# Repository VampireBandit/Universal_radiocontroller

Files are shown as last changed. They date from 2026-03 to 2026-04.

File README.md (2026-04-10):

# Transceiver_101
This is a universal remote controller for almost any remote device e.g. Planes,drones,boats or rc cars. It can be mounted and set up in any custom project the needs remote controlling.
---
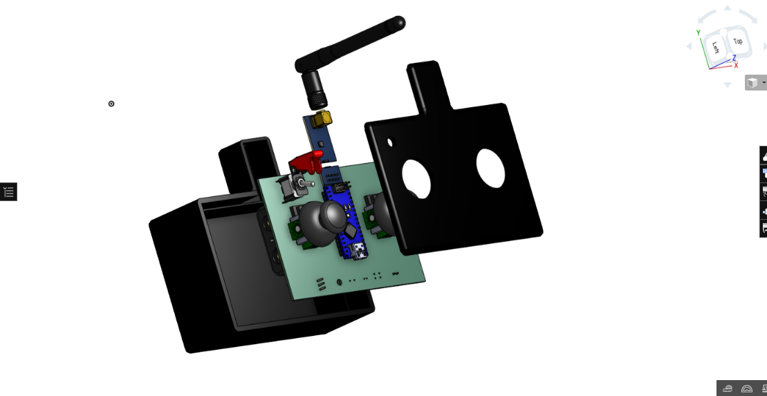
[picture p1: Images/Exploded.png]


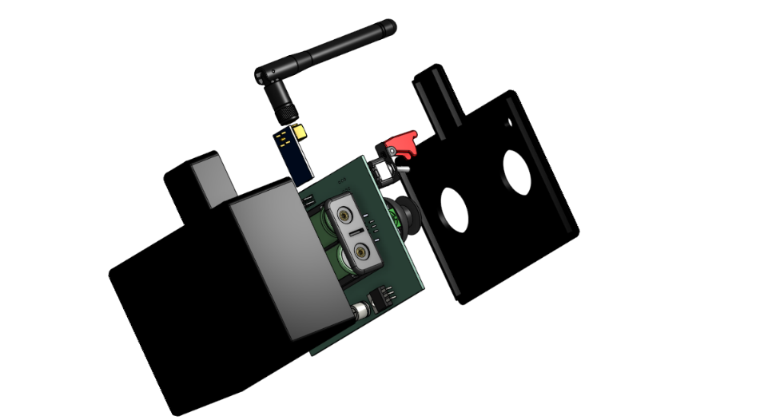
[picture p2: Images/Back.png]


# Key Features 
-can be used to controll almost any project

-customisable for drone flight controllers

-6 channel controller

-up to 2.5km range 

-2 customizable toggle switch

-Custom code to change as needed

# Images

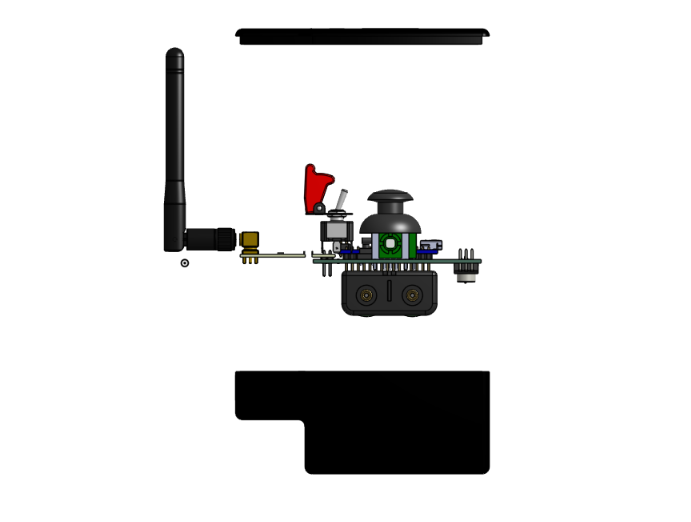
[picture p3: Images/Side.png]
h


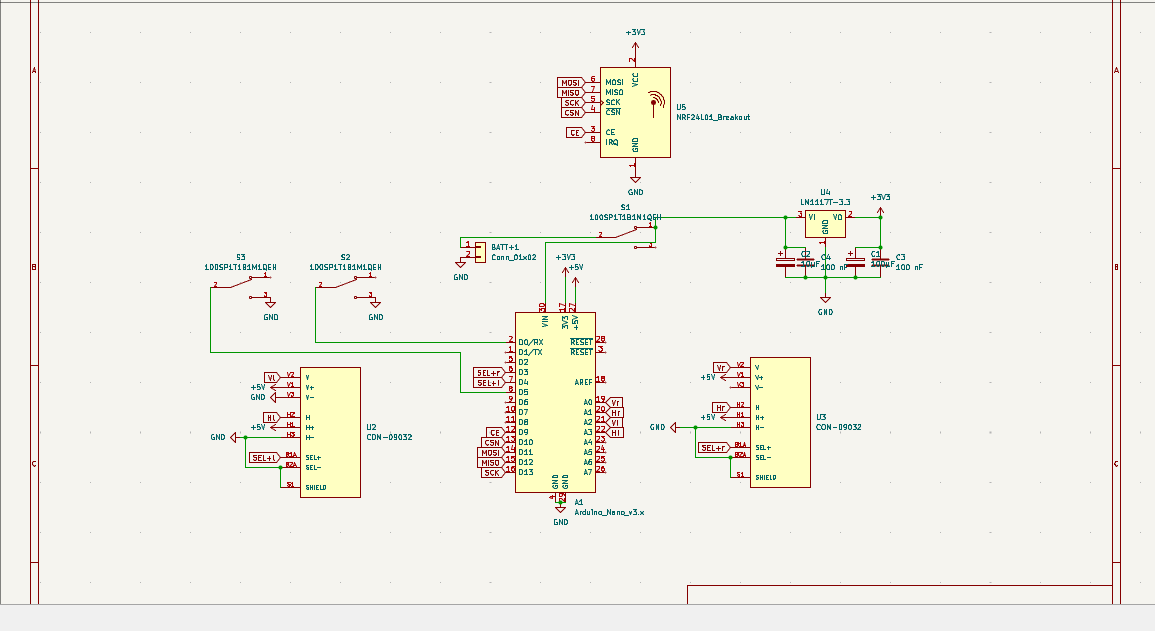
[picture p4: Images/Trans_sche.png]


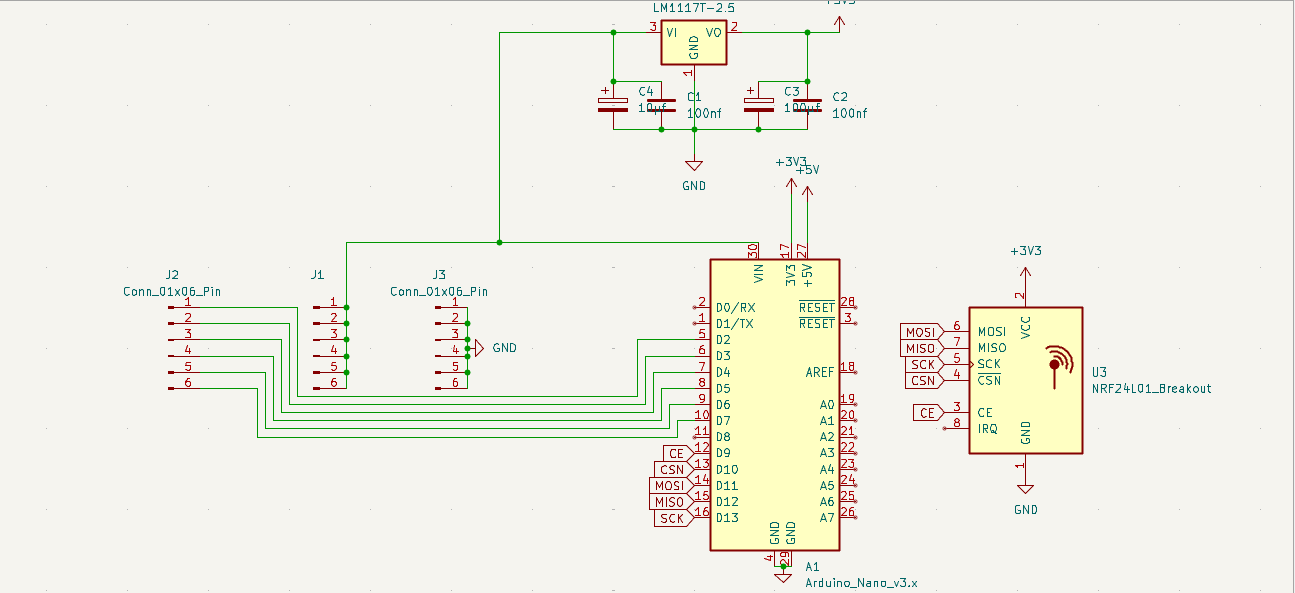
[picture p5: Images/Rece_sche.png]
v


fvg

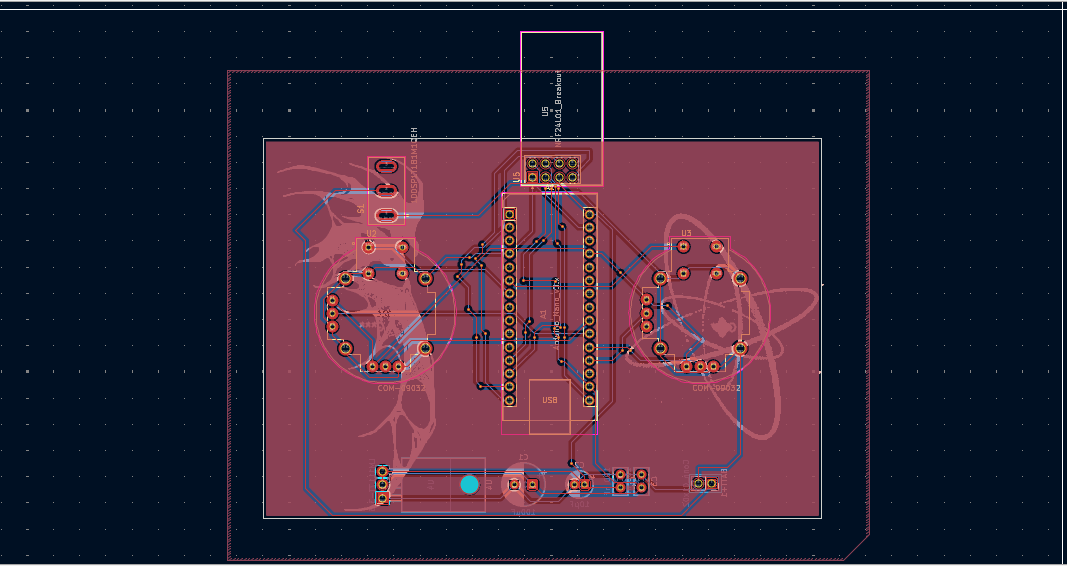
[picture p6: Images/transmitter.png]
g


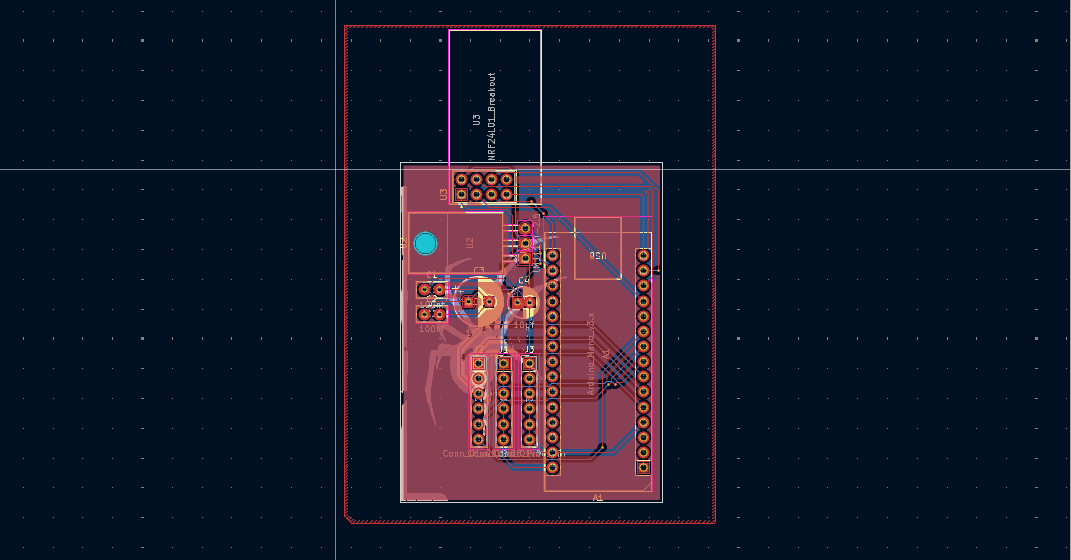
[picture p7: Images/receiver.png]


There is a notch that shuold be kept in mind. 

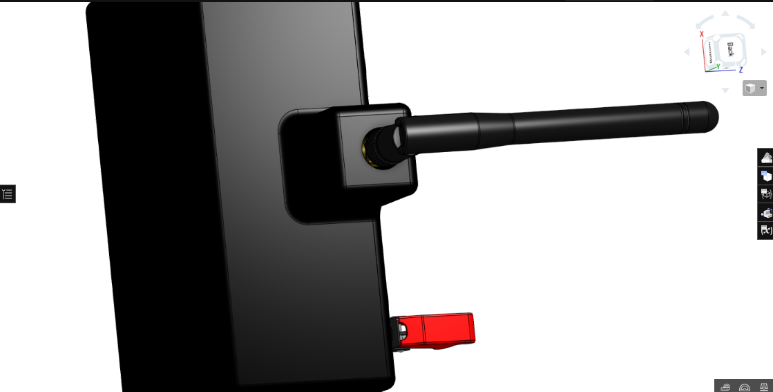
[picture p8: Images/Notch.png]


# BOM

| Name | Purpose | Quantity |
| :--- | :--- | :--- |
| **Toggle switch** | Master power | 1 |
| **PCB** | Circuit board | 2 |
| **Enclosure** | The casing | 1 |
| **Battery** | Power | 2 |
| **Male headers** | Connection | 8 |
| **Female Headers** | Mounting | 56 |
| **100nf capacitor** | Voltage capping | 4 |
| **10uf capacitor** | Voltage regulation | 2 |
| **100uf capacitor** | Voltage regulation | 2 |
| **Arduino Nano** | MCU | 2 |
| **Antenna** | Receiver antenna | 1 |
| **Receiver Module** | Radio transmission | 1 |
| **LM1117T-3.3** | Voltage regulator | 2 |
| **Toggle switch** | Channel switch | 2 |
| **PS4 Analog** | Controlling | 2 |

# Firmware
This remote and receiver uses C++ that is for arduino IDE

Made by Rubaiyat Islam

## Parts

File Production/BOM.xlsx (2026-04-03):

Component | Link | Quantity | Unit Price | Total | With Shipping
Arduino Nano | https://s.click.aliexpress.com/e/_DlhwLS3 | X2 | $2.07 | $4.14 | $4.64
NRF24L01+PA+LN 100mW (E01-ML01DP5) | https://s.click.aliexpress.com/e/_DmEoWQf | X1 | $4.37 | $4.37 | $8.44
NRF24L01+PA+Wireless SMD | https://www.aliexpress.com/item/4001032051571.html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 | X1 | $2.11 | $2.11 | $5.62
100uF (16V or above) electrolytic capacitors | https://s.click.aliexpress.com/e/_Ddfia2R | X2 | $1.02 | $2.04 | $3.00
10uF electrolytic capacitors | https://www.aliexpress.com/item/32910379011.html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"order"%3A"1377"%2C"spu_best_type"%3A"price"%2C"eval"%3A"1"%2C"sceneId"%3A"30050"%2C"fromPage"%3A"recommend"%7D&pdp_npi=6%40dis%21USD%210.73%210.66%21%21%210.73%210.66%21%40210385a817732371508048925e73f6%2112000027302961998%21rec%21BD%217350065947%21X%211%210%21n_tag%3A-29911%3Bd%3A8c992529%3Bm03_new_user%3A-29895&utparam-url=scene%3ApcDetailTopMoreOtherSeller%7Cquery_from%3A%7Cx_object_id%3A32910379011%7C_p_origin_prod%3A | X2 | $0.89 | $1.78 | $2.76
100nF (104) ceramic capacitor | https://www.aliexpress.com/item/1005008483990919.html?pdp_ext_f=%7B"order"%3A"2331"%2C"eval"%3A"1"%2C"fromPage"%3A"search"%7D&pdp_npi=6%40dis%21USD%210.44%210.40%21%21%213.03%212.73%21%402140c1e917732495509002759e5e46%2112000045347461268%21sea%21BD%217350065947%21X%211%210%21n_tag%3A-29911%3Bd%3A8c992529%3Bm03_new_user%3A-29895&curPageLogUid=Py6DamOLkBbD&utparam-url=scene%3Asearch%7Cquery_from%3A%7Cx_object_id%3A1005008483990919%7C_p_origin_prod%3A | X2 | $0.43 | $0.86 | $1.47
LM1117 3.3 RegACulator IC | https://www.aliexpress.com/item/1005003271197114.html?pdp_ext_f=%7B"order"%3A"8"%2C"eval"%3A"1"%2C"fromPage"%3A"search"%7D&pdp_npi=6%40dis%21USD%216.04%216.04%21%21%216.04%216.04%21%40211b65de17732372615652759ea03c%2112000026915350926%21sea%21BD%217350065947%21X%211%210%21n_tag%3A-29911%3Bd%3A8c992529%3Bm03_new_user%3A-29895&curPageLogUid=09Xqtkg0wL0p&utparam-url=scene%3Asearch%7Cquery_from%3A%7Cx_object_id%3A1005003271197114%7C_p_origin_prod%3A | X2 | $6.72 | $13.44 | $13.44
2×4 pin Header | https://www.aliexpress.com/item/4000062424172.html?pdp_ext_f=%7B"order"%3A"4"%2C"eval"%3A"1"%2C"fromPage"%3A"search"%7D&pdp_npi=6%40dis%21USD%213.35%212.85%21%21%213.35%212.85%21%402103891017732373337637330ede3c%2110000000158969144%21sea%21BD%217350065947%21X%211%210%21n_tag%3A-29911%3Bd%3A8c992529%3Bm03_new_user%3A-29895&curPageLogUid=POZyNLQOmYaK&utparam-url=scene%3Asearch%7Cquery_from%3A%7Cx_object_id%3A4000062424172%7C_p_origin_prod%3A | X2 | $2.85 | $5.70 | $14.86
2.4G Antenna Adapter Cable | https://www.aliexpress.com/item/4001032051571.html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 | X2 | $1.24 | $2.48 | $4.75
Toggle switch with plastic cover | https://www.aliexpress.com/item/32858842031.html?pdp_ext_f=%7B"order"%3A"1446"%2C"eval"%3A"1"%2C"fromPage"%3A"search"%7D&pdp_npi=6%40dis%21USD%214.57%214.57%21%21%214.57%214.57%21%4021010d9017732489828965303ef2fc%2112000029766731590%21sea%21BD%217350065947%21X%211%210%21n_tag%3A-29911%3Bd%3A8c992529%3Bm03_new_user%3A-29895&curPageLogUid=x4X8XtIfAjth&utparam-url=scene%3Asearch%7Cquery_from%3A%7Cx_object_id%3A32858842031%7C_p_origin_prod%3A | X1 | $5.85 | $5.85 | $5.85
Male Headers | https://www.aliexpress.com/item/1005010337310648.html?pdp_ext_f=%7B"order"%3A"185"%2C"eval"%3A"1"%2C"fromPage"%3A"search"%7D&pdp_npi=6%40dis%21USD%2112.40%215.95%21%21%2184.68%2140.65%21%402140f54217732497921803080ee878%2112000052031729113%21sea%21BD%217350065947%21X%211%210%21n_tag%3A-29911%3Bd%3A8c992529%3Bm03_new_user%3A-29895&curPageLogUid=9He54BdZktP2&utparam-url=scene%3Asearch%7Cquery_from%3A%7Cx_object_id%3A1005010337310648%7C_p_origin_prod%3A | X20 | $0.33 | $6.61 | $4.63
Bottom Casing |  | X1 |  |  | $12.07
Top Casing |  | X1 |  |  | $3.95
Transmitter PCB |  | X1 |  |  | $7.10
Receiver PCB |  | X1 |  |  | $4.00
General Toggle Switch | https://www.aliexpress.com/item/1005010352006465.html?pdp_ext_f=%7B"order"%3A"282"%2C"eval"%3A"1"%2C"fromPage"%3A"search"%7D&pdp_npi=6%40dis%21USD%2117.28%212.29%21%21%21118.28%2115.70%21%402140f53817752205575296309e4e68%2112000052087737430%21sea%21BD%210%21ABX%211%210%21n_tag%3A-29910%3Bd%3A8c992529%3Bm03_new_user%3A-29895%3BpisId%3A5000000203797608&curPageLogUid=lw18lO9RrN7K&utparam-url=scene%3Asearch%7Cquery_from%3A%7Cx_object_id%3A1005010352006465%7C_p_origin_prod%3A | X2 | $4.96 | $10.00 | $10.00
Grand total |  |  |  |  | $106.58

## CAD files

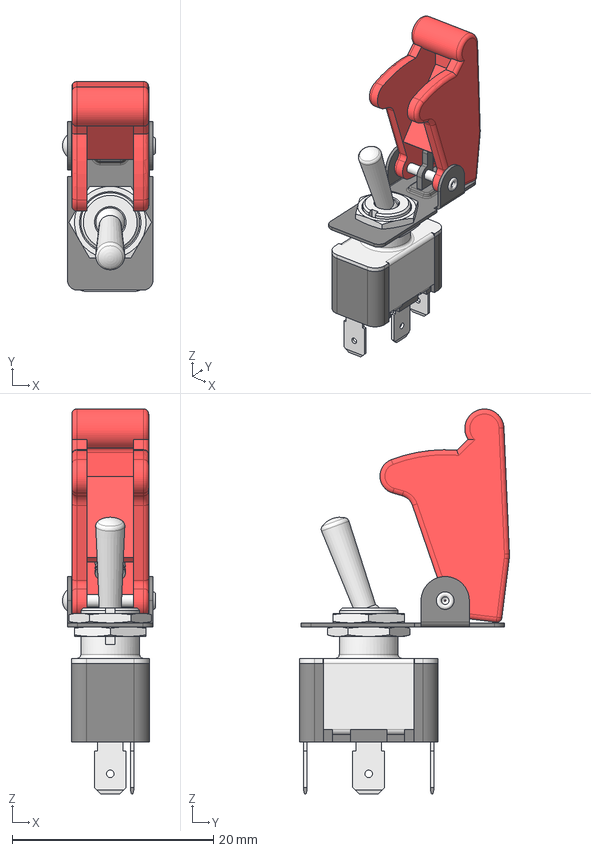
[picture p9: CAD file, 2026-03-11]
CAD/Switch With Guard.step
9.25 x 20.9 x 38.3 mm

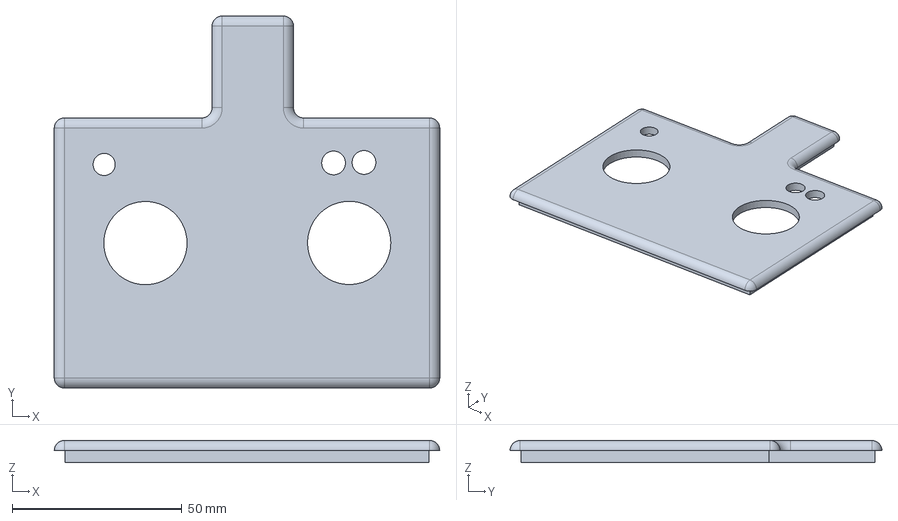
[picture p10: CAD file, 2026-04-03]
Production/TOp.step
113.5 x 109.5 x 6.50 mm

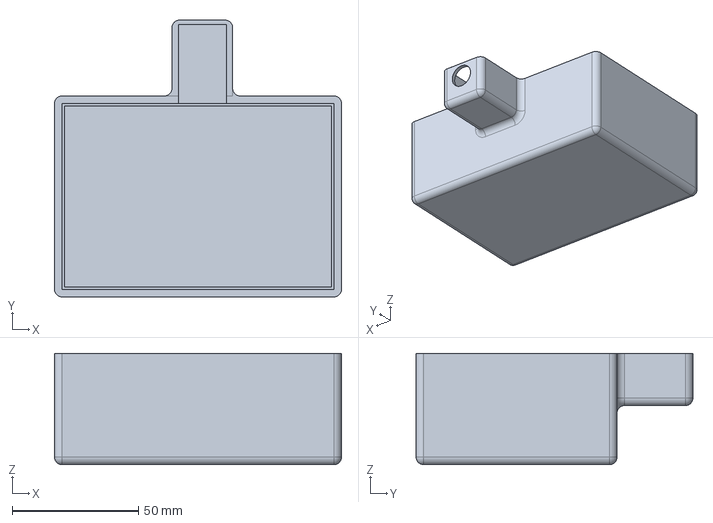
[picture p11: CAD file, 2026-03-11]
CAD/Bottom.step
113.5 x 109.5 x 44.0 mm

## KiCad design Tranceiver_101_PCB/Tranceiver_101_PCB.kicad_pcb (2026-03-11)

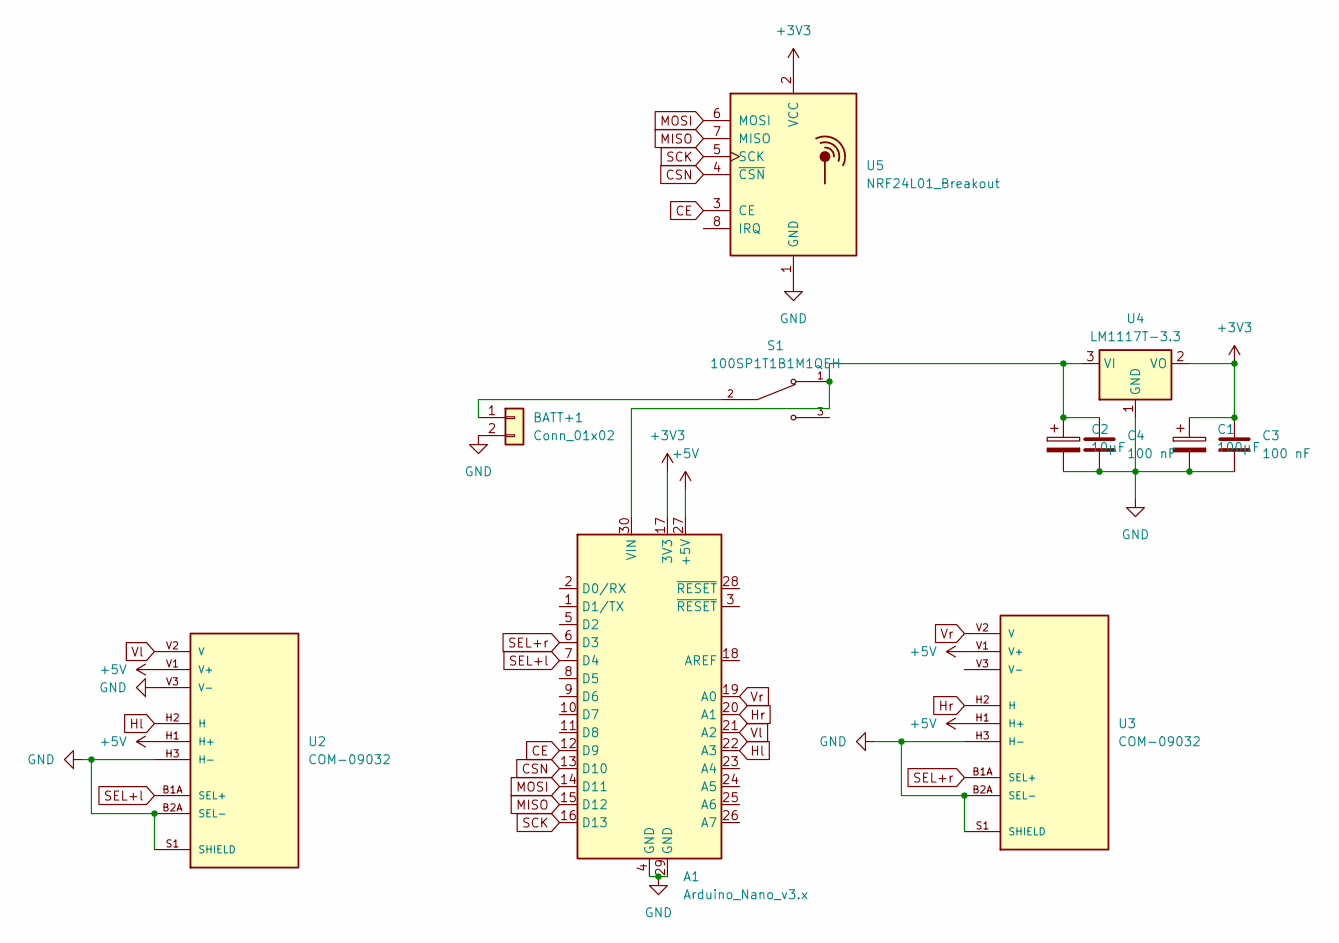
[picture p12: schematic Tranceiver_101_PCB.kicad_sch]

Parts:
A1: Arduino_Nano_v3.x; Arduino_Nano
BATT+1: Conn_01x02; PinHeader_1x02_P2.54mm_Vertical
C1: 100µF; CP_Radial_D8.0mm_P3.50mm
C2: 10µF; CP_Radial_D5.0mm_P2.00mm
C3, C4: 100 nF; C_Disc_D5.0mm_W2.5mm_P2.50mm
S1: 100SP1T1B1M1QEH; SW_100SP1T1B1M1QEH; PARTREV D
U2, U3: COM-09032; XDCR_COM-09032; PARTREV N/A
U4: LM1117T-3.3; TO-220-3_Horizontal_TabDown
U5: NRF24L01_Breakout; nRF24L01_Breakout

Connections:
+3V3: A1.17 (3V3), C1.1, C3.1, U4.2 (VO), U5.2 (VCC)
+5V: A1.27 (+5V), U2.H1 (H+), U2.V1 (V+), U3.H1 (H+), U3.V1 (V+)
CE: A1.12 (D9), U5.3 (CE)
CSN: A1.13 (D10), U5.4 (~CSN)
GND: A1.4 (GND), A1.29 (GND), BATT+1.2, C1.2, C2.2, C3.2, C4.2, U2.B2A (SEL-), U2.H3 (H-), U2.S1 (SHIELD), U2.S2 (SHIELD), U2.S3 (SHIELD), U2.S4 (SHIELD), U2.V3 (V-), U3.B2A (SEL-), U3.H3 (H-), U3.S1 (SHIELD), U3.S2 (SHIELD), U3.S3 (SHIELD), U3.S4 (SHIELD), U4.1 (GND), U5.1 (GND)
Hl: A1.22 (A3), U2.H2 (H)
Hr: A1.20 (A1), U3.H2 (H)
MISO: A1.15 (D12), U5.7 (MISO)
MOSI: A1.14 (D11), U5.6 (MOSI)
unnamed: A1.30 (VIN), C2.1, C4.1, S1.1, U4.3 (VI)
unnamed: BATT+1.1, S1.2
SCK: A1.16 (D13), U5.5 (SCK)
SEL+l: A1.7 (D4), U2.B1A (SEL+)
SEL+r: A1.6 (D3), U3.B1A (SEL+)
Vl: A1.21 (A2), U2.V2 (V)
Vr: A1.19 (A0), U3.V2 (V)

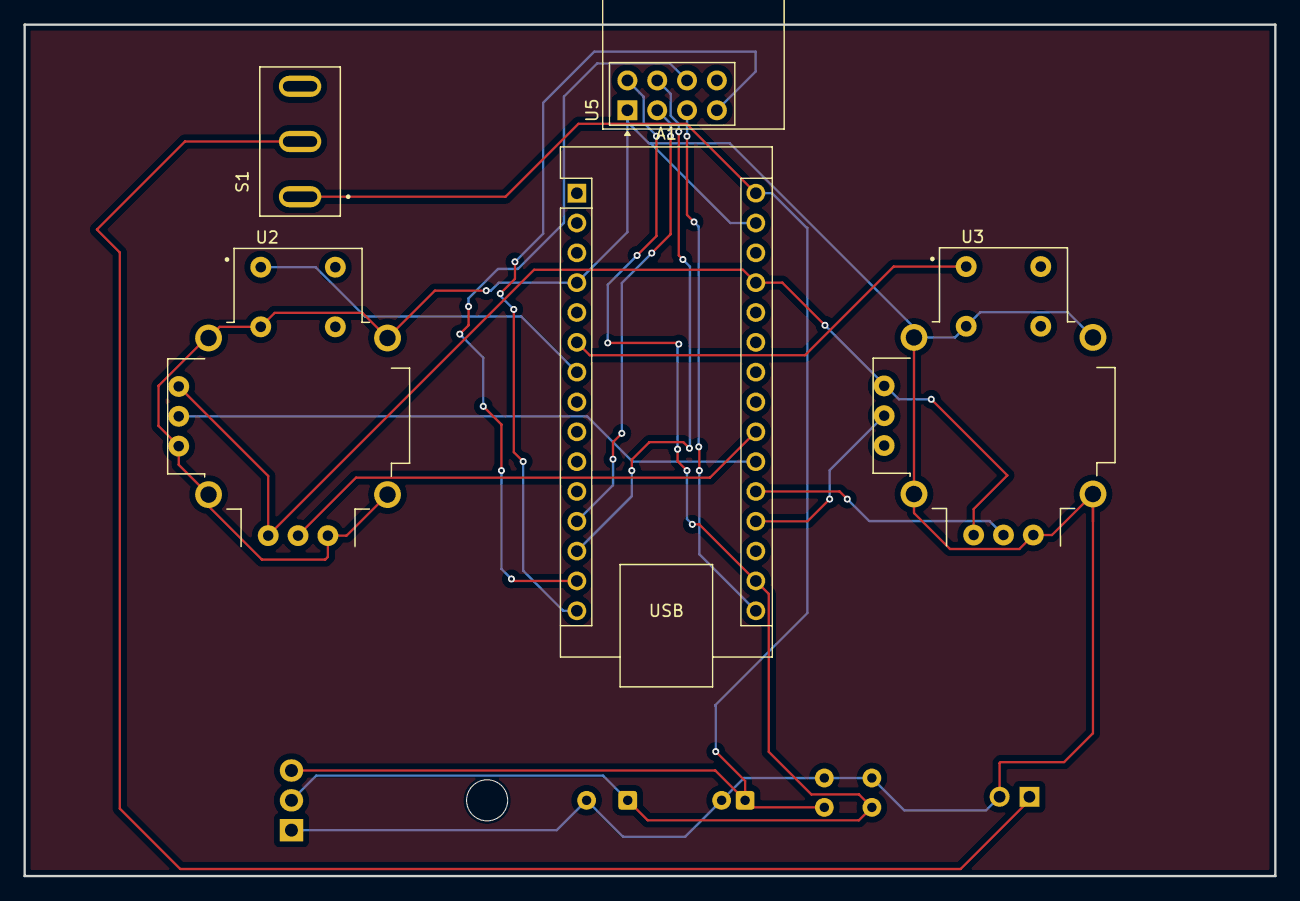
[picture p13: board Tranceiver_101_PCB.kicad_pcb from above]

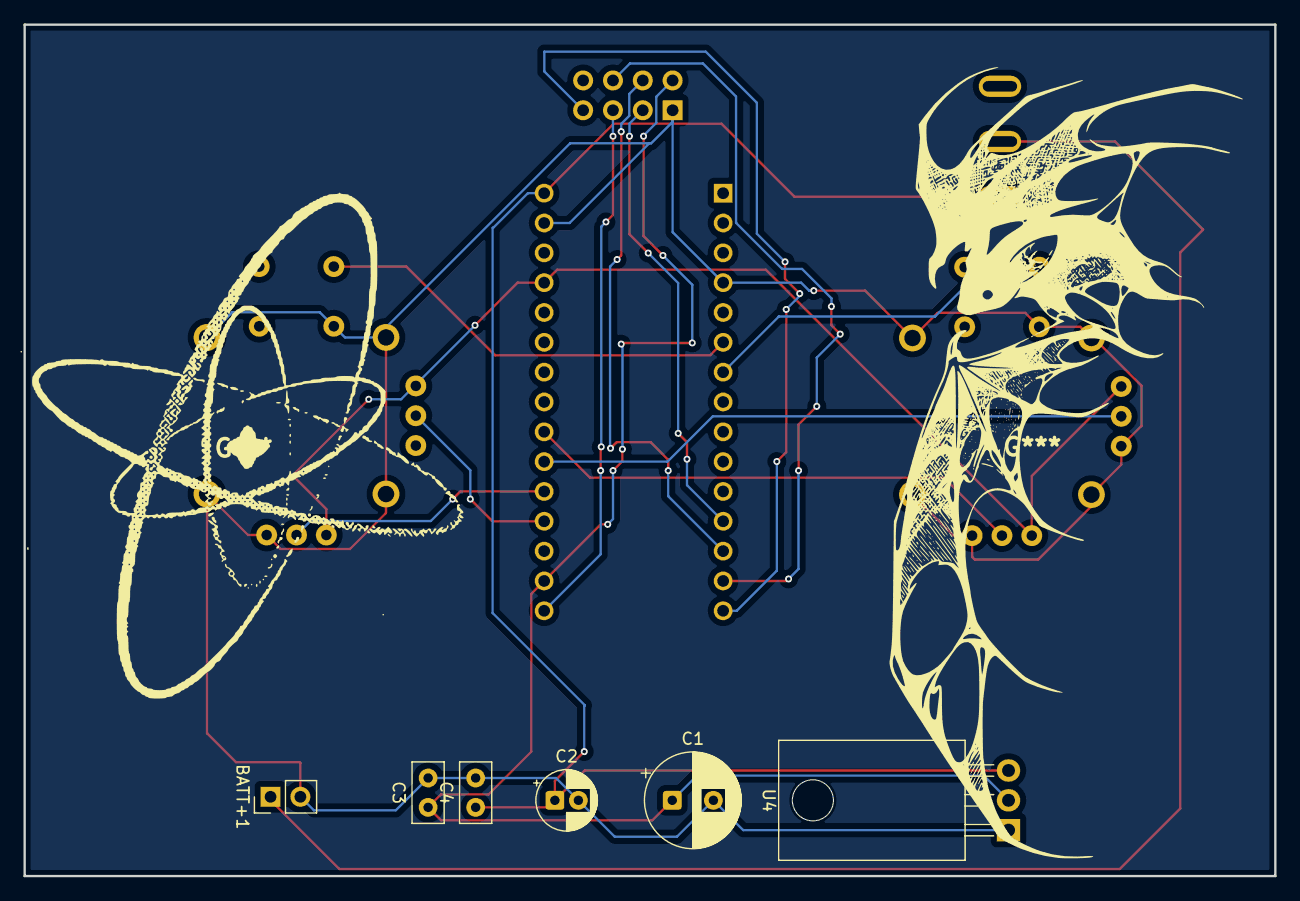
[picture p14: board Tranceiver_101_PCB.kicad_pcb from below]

Board: 2 copper layers, 106.5 x 72.5 mm, 11 parts (6 on the bottom side), 16 nets.

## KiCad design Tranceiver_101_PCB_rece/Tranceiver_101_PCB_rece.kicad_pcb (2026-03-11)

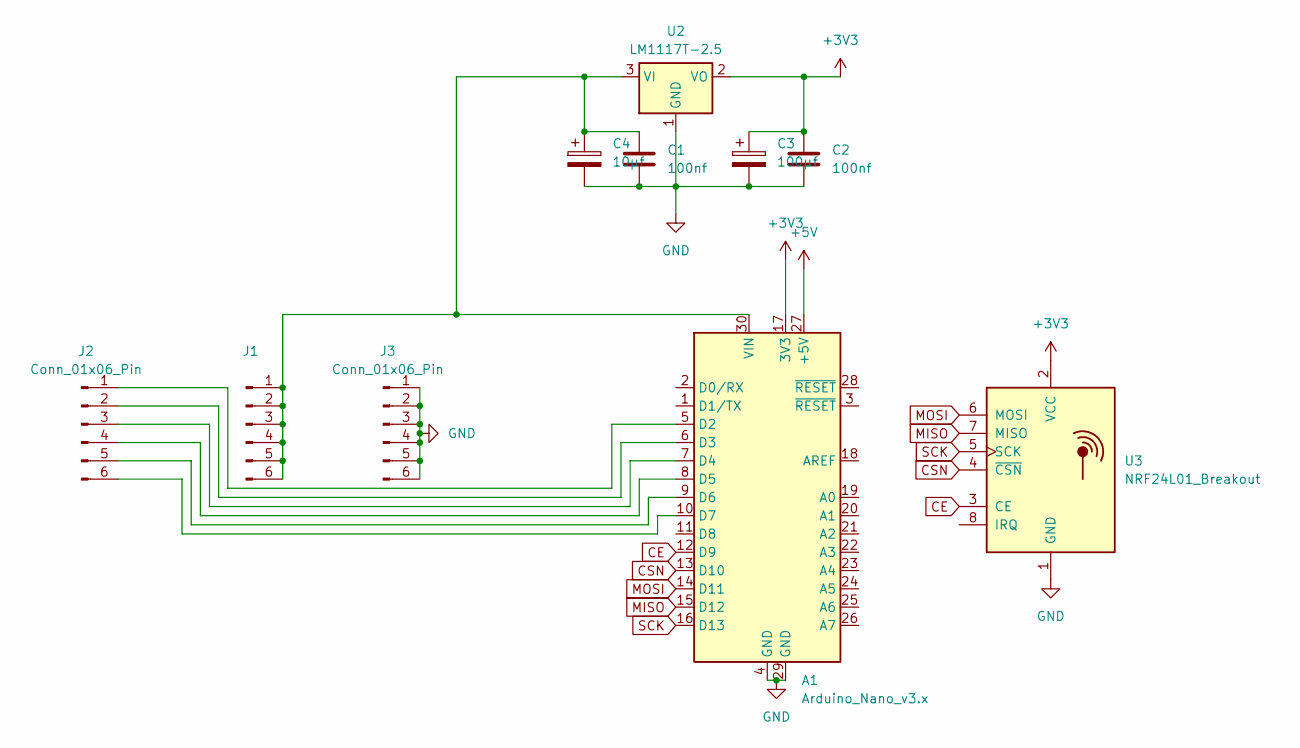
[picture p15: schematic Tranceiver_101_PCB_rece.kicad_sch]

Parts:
A1: Arduino_Nano_v3.x; Arduino_Nano
C1, C2: 100nf; C_Disc_D5.0mm_W2.5mm_P2.50mm
C3: 100μf; CP_Radial_D8.0mm_P3.50mm
C4: 10μf; CP_Radial_D5.0mm_P2.00mm
J1, J2, J3: Conn_01x06_Pin; PinHeader_1x06_P2.54mm_Vertical
U2: LM1117T-2.5; TO-220-3_Horizontal_TabDown
U3: NRF24L01_Breakout; nRF24L01_Breakout

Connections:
+3V3: A1.17 (3V3), C2.1, C3.1, U2.2 (VO), U3.2 (VCC)
+5V: A1.27 (+5V)
CE: A1.12 (D9), U3.3 (CE)
CSN: A1.13 (D10), U3.4 (~CSN)
GND: A1.4 (GND), A1.29 (GND), C1.2, C2.2, C3.2, C4.2, J3.1, J3.2, J3.3, J3.4, J3.5, J3.6, U2.1 (GND), U3.1 (GND)
MISO: A1.15 (D12), U3.7 (MISO)
MOSI: A1.14 (D11), U3.6 (MOSI)
unnamed: A1.5 (D2), J2.1
unnamed: A1.6 (D3), J2.2
unnamed: A1.7 (D4), J2.3
unnamed: A1.8 (D5), J2.4
unnamed: A1.9 (D6), J2.5
unnamed: A1.10 (D7), J2.6
unnamed: A1.30 (VIN), C1.1, C4.1, J1.1, J1.2, J1.3, J1.4, J1.5, J1.6, U2.3 (VI)
SCK: A1.16 (D13), U3.5 (SCK)

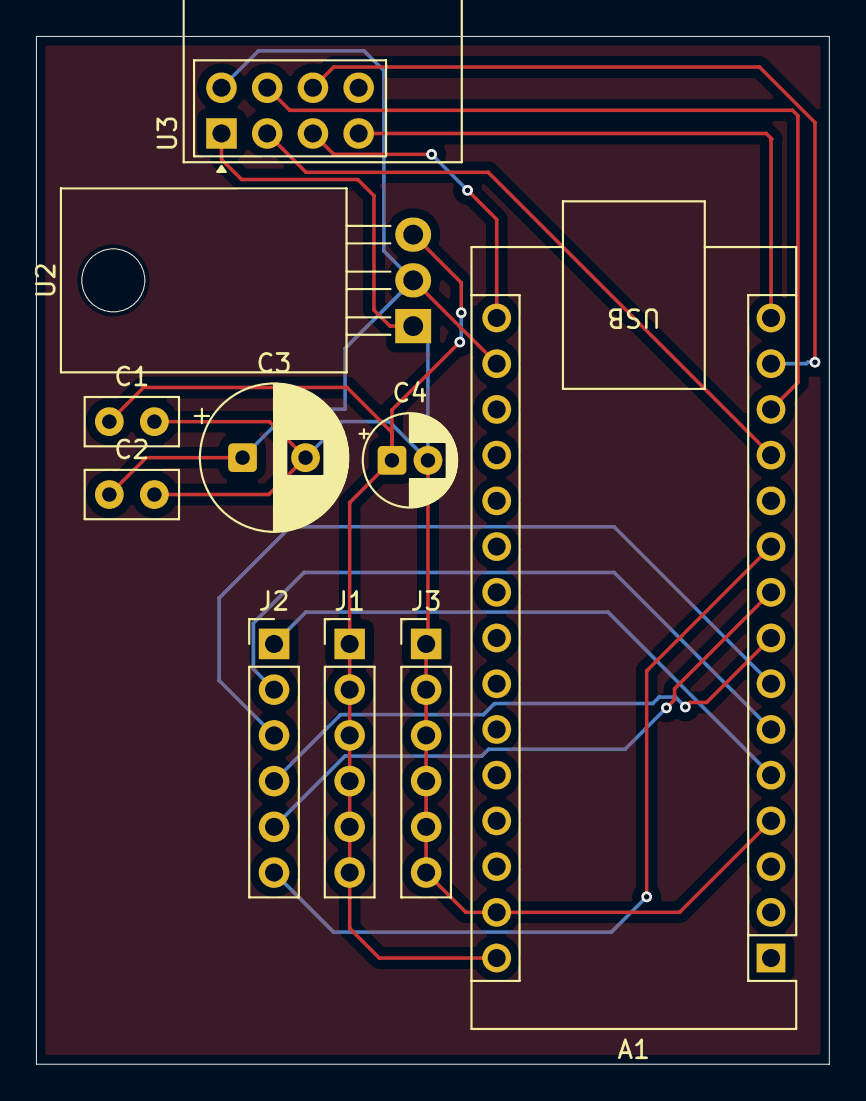
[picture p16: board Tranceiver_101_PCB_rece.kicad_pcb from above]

Board: 2 copper layers, 44.1 x 57.1 mm, 10 parts (0 on the bottom side), 14 nets.

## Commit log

2026-03-11 Needed to add switch
    [Bottom.step, Top.step]
2026-03-11 Added a line to fit jlc
    [Top.step]
2026-04-10 Revise BOM section in README.md
    Updated parts list for the project and removed redundant items.
